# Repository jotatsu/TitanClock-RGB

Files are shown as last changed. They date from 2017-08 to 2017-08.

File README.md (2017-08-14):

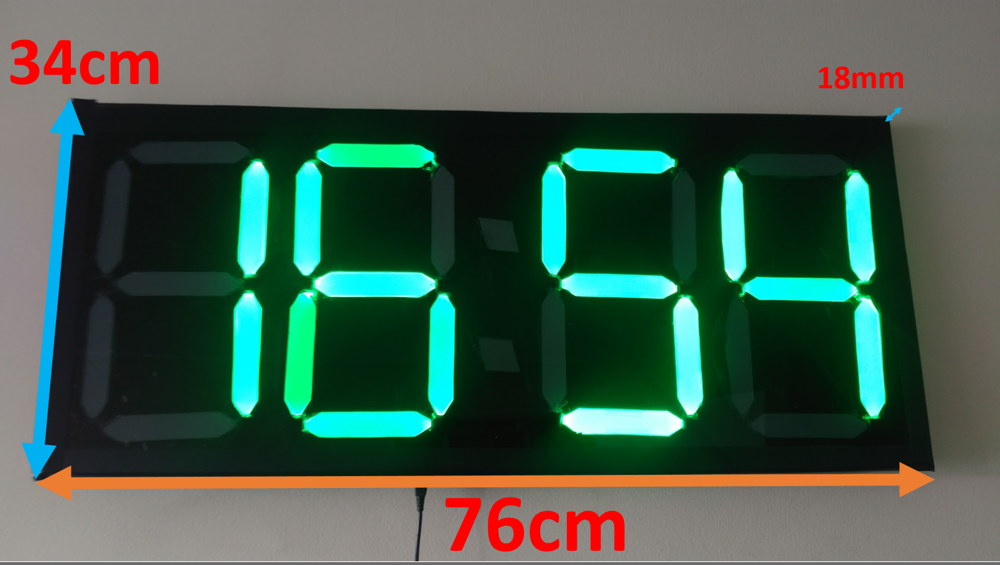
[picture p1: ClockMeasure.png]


# Titan Clock RGB

Base code and schemes for a very large RGB wall clock.

## Inspiration
There are many great DIY projects on the internet on how to do very large 7 digit display clocks, I've been trying to do my own for years also but always come short of good results. Now i've something decent and i think this are the advantages over other projects:

- Cheap: The components of this project on worse case scenario should not cost above 50 usd. 
- Large: It's a wall clock, you want them as large as possible.
- Efficient: Some of the clocks I’ve seen use 10w or above, the objective of this clock was that it will run on a smartphone charger, that means normally 5w or less (with the normal adjustments it runs between 800mw and 2.5w).
- Uniform: I want the digits to glow in a uniform light. some of the techniques I’ve seen to create this 7 segment display create brighter and darker spots because of the nature of led light and diffusion.
- Thin: Given the last point, one of the most common techniques is use separation between the led and the front of the display, making them thick. This clock is very thin (10mm for the digit and 18 mm with casing)
- Extendable. The current version of Titan RGB clock does simple by hour color change according to a predetermined table. However, the display can be controllable per segment with decent refresh rate, that means animations. You just need to upgrade the soft in the controller or change the controller. 

## Materials 
- Arduino nano, the cable for programming and connecting to the charger
- 1 ds3231 module for arduino 
- 1 1000 µF, 6.3V or higher. As recommended for using the rgb leds in a string. 
- 56 ws2812b or similar rgb leds in 5050 or 3030 package, I’m using the mini breakout boards to help with soldering.
- 1 smartphone charger
- 1 damaged lcd monitor or tv, older ones are better as they have thicker diffuser sheets that fit the 5050 profile.
- 1 transparent acrylic sheet, the size of your display
- 1 sheet of polarized film, the ones used for car tinting, i used 35%.
- Lots of cables to wire the segments
- Foamcore board, wood or any other base material for the box of the clock.  

Optional

- 4x 3 Pin jst sm connector or similar to make your display modular and not soldering them to the arduino 
 
Tools
- Soldering iron and solder
- Wire stripper 
- Saw for acrylic, but I recommend using laser to get optical quality cuts.  
- Glue

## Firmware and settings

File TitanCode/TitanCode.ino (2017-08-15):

/*
 * Copyright (C) 2017 Camilo Alvarez - ProtheanSoft
 * 
 * Licensed under the Apache License, Version 2.0 (the "License");
 * you may not use this file except in compliance with the License.
 * You may obtain a copy of the License at
 * 
 * http://www.apache.org/licenses/LICENSE-2.0
 * 
 * Unless required by applicable law or agreed to in writing, software
 * distributed under the License is distributed on an "AS IS" BASIS,
 * WITHOUT WARRANTIES OR CONDITIONS OF ANY KIND, either express or implied.
 * See the License for the specific language governing permissions and
 * limitations under the License.
 */

//RTC libraries 
#include <Wire.h> 
#include <Adafruit_NeoPixel.h>
#include "DS3231.h"
//WS2812B libraries

#ifdef __AVR__
  #include <avr/power.h>
#endif

/**************RGB strip Definitions**************/

// Define pins for led strip
#define PIN            9
#define PINBLINK       6

// Define pixels in the strip
#define NUMPIXELS      56
#define NUMPIXELS3     2

//Setup led strips
Adafruit_NeoPixel pixels = Adafruit_NeoPixel(NUMPIXELS, PIN, NEO_GRB + NEO_KHZ800);
Adafruit_NeoPixel blinks  = Adafruit_NeoPixel(NUMPIXELS3, PINBLINK, NEO_GRB + NEO_KHZ800);


/**************RTC Definitions**************/
RTClib rtc;
 


/*******Control states for the clock********/
int delayval = 1000; 

int hourDigit1=0;
int hourDigit2=0;
int miniteDigit1=0;
int miniteDigit2=0;

int blinkState=0;
/////*Globals*/////

#define SEGMENT_SIZE    14
#define TOTAL_SEGMENTS  4


/////*Number templates*/////
//This define a template for number inside a segment according to the wiring of the project, 
//1 represent the led is on and should be colored
//0 represent that is should be off
//2 leds per segment, 14 leds per number

//Mask for right to left numbers 
unsigned int rgbColourInv[11][14]={
  {1,1,1,0,1,1,1,1,1,1,0,1,1,1}, //0
  {0,1,1,0,1,1,0,0,0,0,0,0,0,0}, //1
  {1,0,0,1,1,1,1,1,0,0,1,1,1,1}, //2
  {1,1,1,1,1,1,1,1,0,0,1,0,0,1}, //3
  {0,1,1,1,1,1,0,0,1,1,1,0,0,0}, //4
  {1,1,1,1,0,0,1,1,1,1,1,0,0,1}, //5
  {1,1,1,1,0,0,1,1,1,1,1,1,1,1}, //6
  {0,1,1,0,1,1,1,1,0,0,0,0,0,0}, //7
  {1,1,1,1,1,1,1,1,1,1,1,1,1,1}, //8
  {0,1,1,1,1,1,1,1,1,1,0,0,0,0}, //9
  {0,0,0,0,0,0,0,0,0,0,0,0,0,0}, //nill
};

//Mask for left to right numbers 
unsigned int rgbColour[11][14]={
  {1,1,1,0,1,1,1,1,1,1,0,1,1,1}, //0
  {0,0,0,0,0,0,0,0,1,1,0,1,1,0}, //1
  {1,1,1,1,0,0,1,1,1,1,1,0,0,1}, //2
  {1,0,0,1,0,0,1,1,1,1,1,1,1,1}, //3
  {0,0,0,1,1,1,0,0,1,1,1,1,1,0}, //4
  {1,0,0,1,1,1,1,1,0,0,1,1,1,1}, //5
  {1,1,1,1,1,1,1,1,0,0,1,1,1,1}, //6
  {0,0,0,0,0,0,1,1,1,1,0,1,1,0}, //7
  {1,1,1,1,1,1,1,1,1,1,1,1,1,1}, //8
  {0,0,0,0,1,1,1,1,1,1,1,1,1,0}, //9
  {0,0,0,0,0,0,0,0,0,0,0,0,0,0}, //nill
};

//Creates a RGB color schedule by hourR
unsigned int colorSchedule[24][3]= {
  {40,0,0},  //00
  {40,0,0},  //01
  {40,0,0},  //02
  {40,0,0},  //03
  {40,0,0},  //04
  {40,0,0},  //05   
  {180,0,0},  //06
  {180,0,0},  //07
  {160,20,0},  //08
  {140,40,0},  //09
  {120,60,0},  //10
  {100,80,0},  //11
  {80,100,0},  //12
  {60,120,0},  //13
  {40,140,0},  //14
  {20,160,0},  //15
  {0,180,0},  //16
  {0,160,20},  //17
  {0,140,40},  //18
  {0,120,60},  //19
  {0,100,80},  //20
  {0,80,100},  //21
  {40,0,0},  //22
  {40,0,0},  //23
}; 
int currColor[3]= {0,0,160}; 

/////*-------*/////
void setup() {

  pixels.begin(); // This initializes the NeoPixel library.
  blinks.begin(); // This initializes the NeoPixel library.
  Serial.begin(9600); 
  delay(1000); 
  Wire.begin(); 
}

//Set the number's color for a given segment
void setNumber(int number, int segment,  int r,int g,int b)
{
  //Segment are offsets of 14
  int offset = SEGMENT_SIZE * segment;
  
  if(segment < TOTAL_SEGMENTS)
  {
    for (int i = 0 ; i < SEGMENT_SIZE; i++)
    {
      if( rgbColour[number][i] == 0)
      {
         pixels.setPixelColor(i + offset, pixels.Color(0,0,0));  
      }else{
         pixels.setPixelColor(i + offset, pixels.Color(r,g,b));  
      }
    }  
  }
}

//Set the blinking dots color
void setBlink(int r,int g,int b)
{
      blinks.setPixelColor(0, pixels.Color(r,g,b));  
      blinks.setPixelColor(1, pixels.Color(r,g,b));  
}
 
void loop() { 

  DateTime now = rtc.now();

  hourDigit1=now.hour()/10;
  hourDigit2=now.hour()%10;
  miniteDigit1=now.minute()/10;
  miniteDigit2=now.minute()%10;    

  //Serial.println(now.hour()+':'+now.minute()+':'+now.second());
  
  //Color calculation
  currColor[0] = colorSchedule[now.hour()][0];
  currColor[1] = colorSchedule[now.hour()][1];
  currColor[2] = colorSchedule[now.hour()][2];

  //Extra power saving by disabling the first 0 in hours like 09:30
  if (hourDigit1 == 0)
  {
    setNumber(10,0,currColor[0],currColor[1],currColor[2]);
  }else{
    setNumber(hourDigit1,0,currColor[0],currColor[1],currColor[2]);
  }
  setNumber(hourDigit2,1,currColor[0],currColor[1],currColor[2]);
  setNumber(miniteDigit1,2,currColor[0],currColor[1],currColor[2]);
  setNumber(miniteDigit2,3,currColor[0],currColor[1],currColor[2]);
  if(blinkState==0)
  {
    setBlink(currColor[0],currColor[1],currColor[2]);
    blinkState = 1;
  }else
  {
    setBlink(0,0,0);
    blinkState = 0;
  }
  
  pixels.show();
  blinks.show();

  delay(delayval); 
}
